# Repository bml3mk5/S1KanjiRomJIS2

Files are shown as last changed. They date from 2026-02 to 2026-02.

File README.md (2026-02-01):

# JIS第二水準内蔵漢字ROMカード for 日立MB-S1

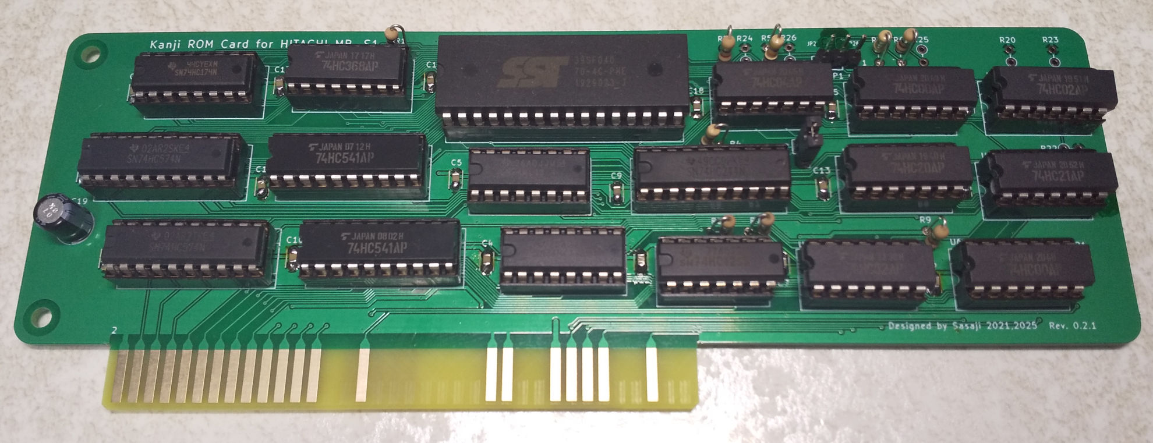
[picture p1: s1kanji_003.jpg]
KanjiROMCard

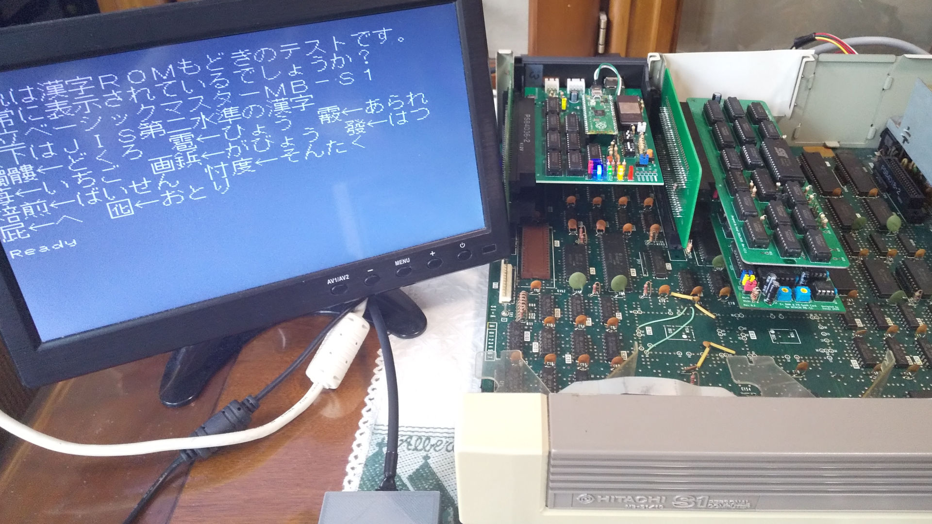
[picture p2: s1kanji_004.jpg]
Install to the MB-S1 and test it


## フォルダ構成

    Board/ ......................... 基板設計
    Documents/ ..................... 説明書など

-----
# JIS Level 2 Kanji Insided Kanji ROM Card for HITACHI MB-S1

## Folders

    Board/ ......................... The circuit board design
    Documents/ ..................... User's Manual etc.

-----
 MailTo: Sasaji (sasaji@s-sasaji.ddo.jp)
 * My Webpage: http://s-sasaji.ddo.jp/bml3mk5/
 * GitHub:     https://github.com/bml3mk5/S1KanjiRomJIS2
 * X(Twitter): https://x.com/bml3mk5

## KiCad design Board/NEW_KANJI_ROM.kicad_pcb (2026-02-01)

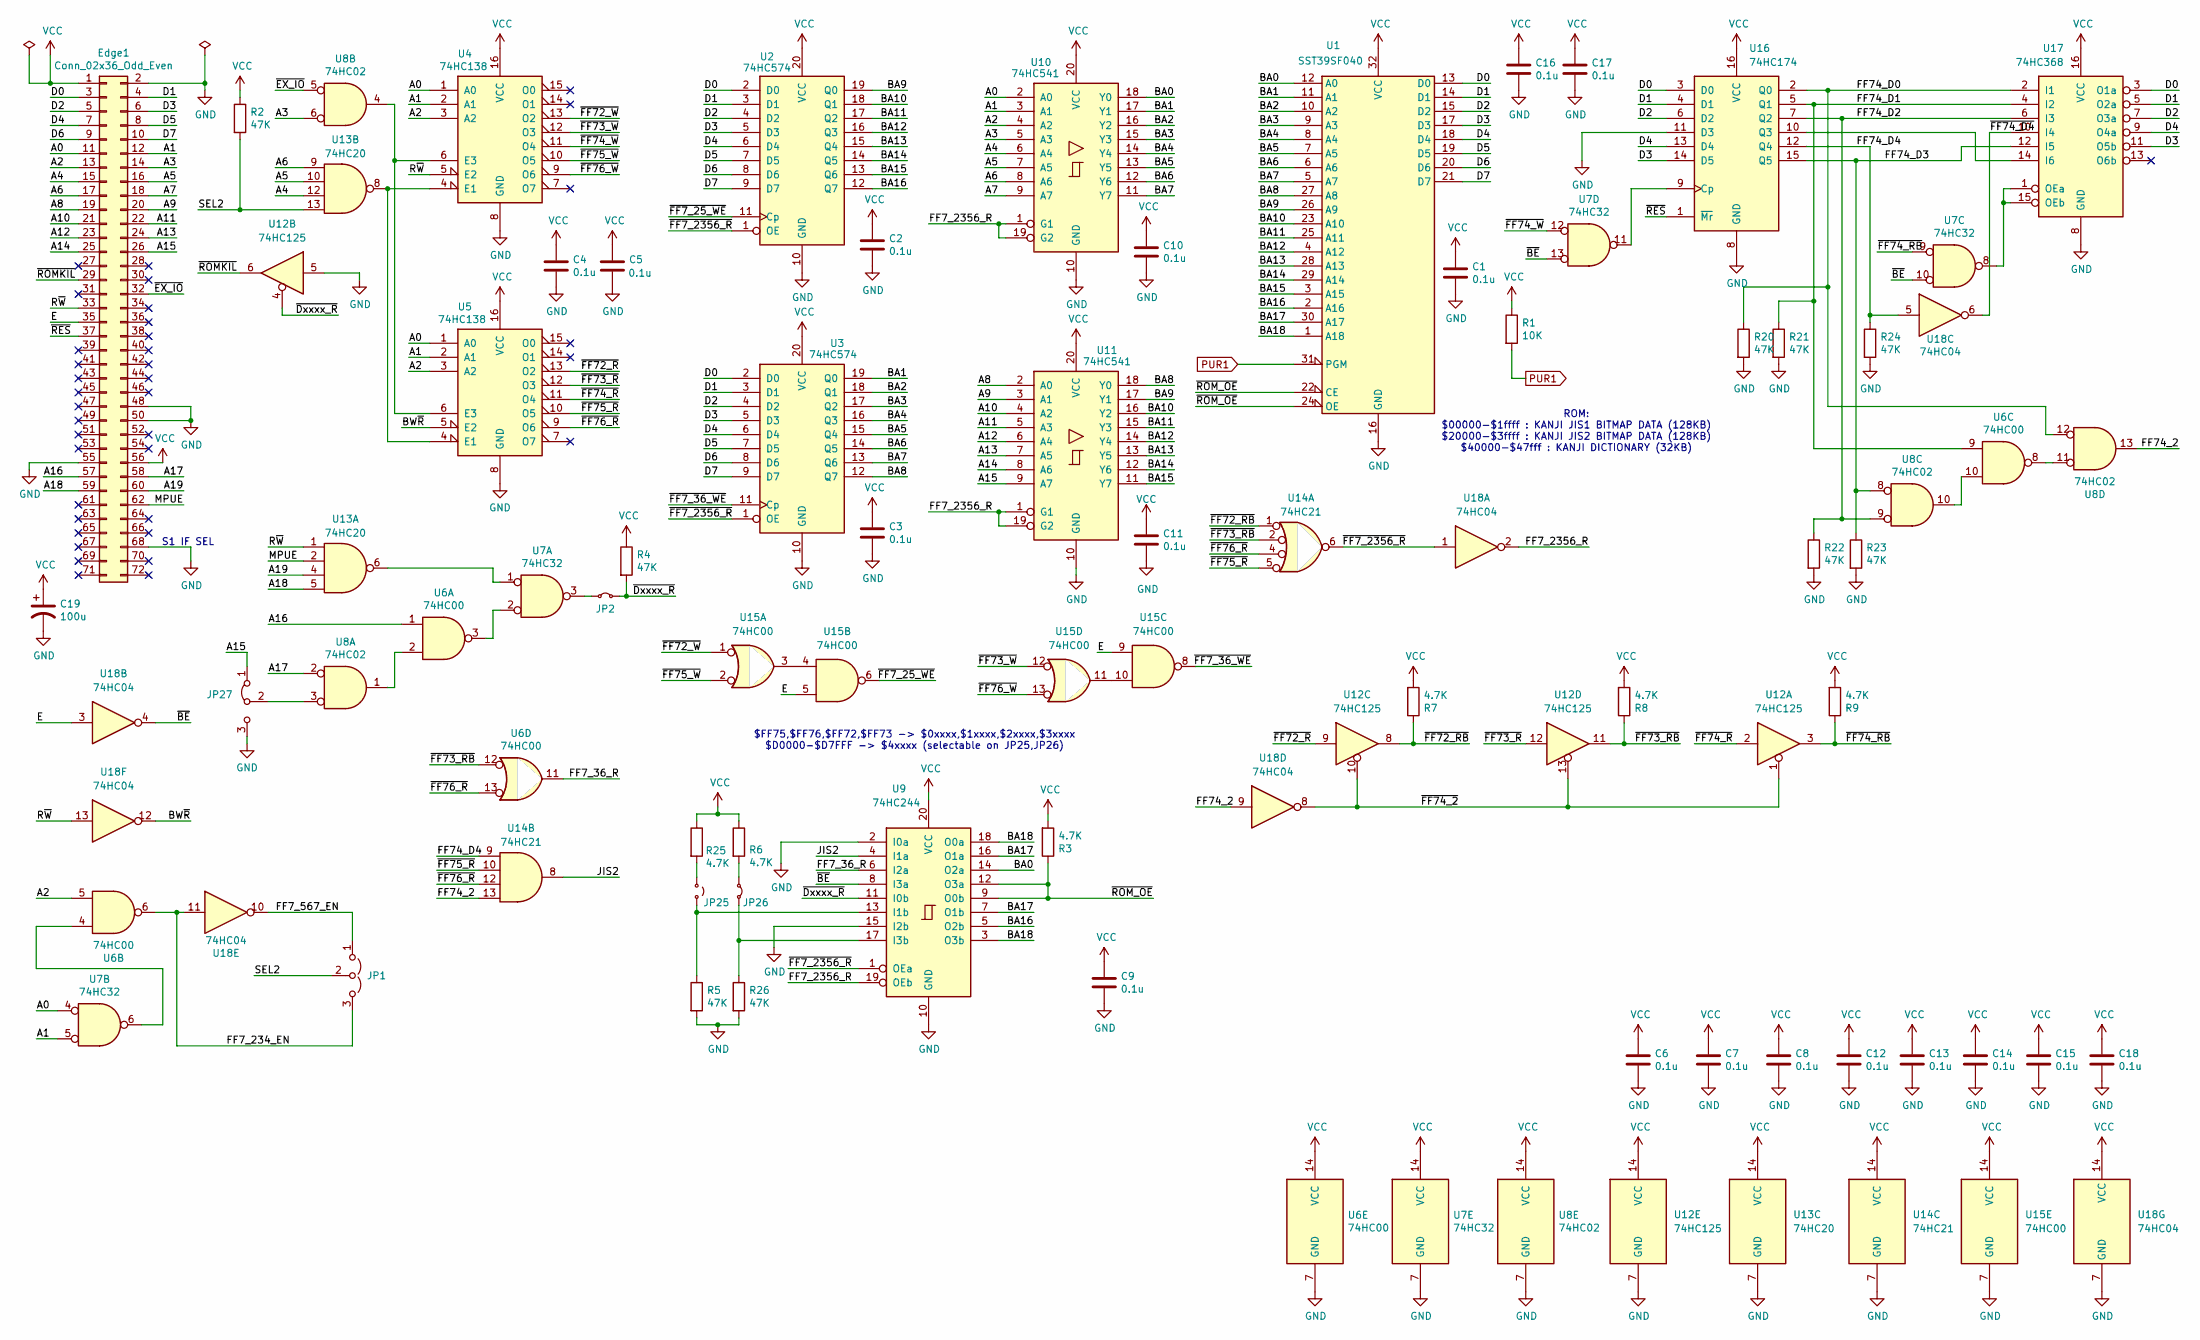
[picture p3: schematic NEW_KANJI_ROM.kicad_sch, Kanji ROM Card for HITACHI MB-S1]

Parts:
C1, C2, C3, C4, C5, C6, C7, C8, C9, C10, C11, C12, C13, C14, C15, C16, C17, C18: 0.1u; C_Disc_D3.0mm_W2.0mm_P2.50mm
C19: 100u; CP_Radial_D6.3mm_P2.50mm
Edge1: Conn_02x36_Odd_Even; CardEdge72T
JP1: Jumper_3_Open; PinHeader_1x03_P2.54mm_Vertical
JP2: Jumper_2_Small_Bridged; PinHeader_1x02_P2.54mm_Vertical
JP25: Jumper_2_Small_Open; My_SolderJumper-2_P1mm_Open_SquarePad0.8x1.0mm
JP26: Jumper_2_Small_Bridged; My_SolderJumper-2_P1mm_Bridged_SquarePad0.8x1.0mm
JP27: Jumper_3_Bridged12; My_SolderJumper-3_P1.3mm_Bridged12_RoundedPad1.0x1.5mm
R1: 10K; R_Axial_DIN0204_L3.6mm_D1.6mm_P2.54mm_Vertical
R2, R4, R5, R20, R21, R22, R23, R24, R26: 47K; R_Axial_DIN0204_L3.6mm_D1.6mm_P2.54mm_Vertical
R3, R6, R7, R8, R9, R25: 4.7K; R_Axial_DIN0204_L3.6mm_D1.6mm_P2.54mm_Vertical
U1: SST39SF040; DIP-32_W15.24mm_Socket
U2, U3: 74HC574; DIP-20_W7.62mm_Socket
U4, U5: 74HC138; DIP-16_W7.62mm_Socket
U6, U15: 74HC00; DIP-14_W7.62mm_Socket
U7: 74HC32; DIP-14_W7.62mm_Socket
U8: 74HC02; DIP-14_W7.62mm_Socket
U9: 74HC244; DIP-20_W7.62mm_Socket
U10, U11: 74HC541; DIP-20_W7.62mm_Socket
U12: 74HC125; DIP-14_W7.62mm_Socket
U13: 74HC20; DIP-14_W7.62mm_Socket
U14: 74HC21; DIP-14_W7.62mm_Socket
U16: 74HC174; DIP-16_W7.62mm_Socket
U17: 74HC368; DIP-16_W7.62mm_Socket
U18: 74HC04; DIP-14_W7.62mm_Socket

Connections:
/A0: Edge1.11, U4.1 (A0), U5.1 (A0), U7.4, U10.2 (A0)
/A1: Edge1.12, U4.2 (A1), U5.2 (A1), U7.5, U10.3 (A1)
/A2: Edge1.13, U4.3 (A2), U5.3 (A2), U6.5, U10.4 (A2)
/A3: Edge1.14, U8.6, U10.5 (A3)
/A4: Edge1.15, U10.6 (A4), U13.12
/A5: Edge1.16, U10.7 (A5), U13.10
/A6: Edge1.17, U10.8 (A6), U13.9
/A7: Edge1.18, U10.9 (A7)
/A8: Edge1.19, U11.2 (A0)
/A9: Edge1.20, U11.3 (A1)
/A10: Edge1.21, U11.4 (A2)
/A11: Edge1.22, U11.5 (A3)
/A12: Edge1.23, U11.6 (A4)
/A13: Edge1.24, U11.7 (A5)
/A14: Edge1.25, U11.8 (A6)
/A15: Edge1.26, JP27.1 (A), U11.9 (A7)
/A16: Edge1.57, U6.1
/A17: Edge1.58, U8.2
/A18: Edge1.59, U13.5
/A19: Edge1.60, U13.4
/BA0: U1.12 (A0), U9.14 (O2a), U10.18 (Y0)
/BA1: U1.11 (A1), U3.19 (Q0), U10.17 (Y1)
/BA2: U1.10 (A2), U3.18 (Q1), U10.16 (Y2)
/BA3: U1.9 (A3), U3.17 (Q2), U10.15 (Y3)
/BA4: U1.8 (A4), U3.16 (Q3), U10.14 (Y4)
/BA5: U1.7 (A5), U3.15 (Q4), U10.13 (Y5)
/BA6: U1.6 (A6), U3.14 (Q5), U10.12 (Y6)
/BA7: U1.5 (A7), U3.13 (Q6), U10.11 (Y7)
/BA8: U1.27 (A8), U3.12 (Q7), U11.18 (Y0)
/BA9: U1.26 (A9), U2.19 (Q0), U11.17 (Y1)
/BA10: U1.23 (A10), U2.18 (Q1), U11.16 (Y2)
/BA11: U1.25 (A11), U2.17 (Q2), U11.15 (Y3)
/BA12: U1.4 (A12), U2.16 (Q3), U11.14 (Y4)
/BA13: U1.28 (A13), U2.15 (Q4), U11.13 (Y5)
/BA14: U1.29 (A14), U2.14 (Q5), U11.12 (Y6)
/BA15: U1.3 (A15), U2.13 (Q6), U11.11 (Y7)
/BA16: U1.2 (A16), U2.12 (Q7), U9.5 (O2b)
/BA17: U1.30 (A17), U9.7 (O1b), U9.16 (O1a)
/BA18: U1.1 (A18), U9.3 (O3b), U9.18 (O0a)
/BW~R: U5.5 (E2), U18.12
/D0: Edge1.3, U1.13 (D0), U2.2 (D0), U3.2 (D0), U16.3 (D0), U17.3 (O1a)
/D1: Edge1.4, U1.14 (D1), U2.3 (D1), U3.3 (D1), U16.4 (D1), U17.5 (O2a)
/D2: Edge1.5, U1.15 (D2), U2.4 (D2), U3.4 (D2), U16.6 (D2), U17.7 (O3a)
/D3: Edge1.6, U1.17 (D3), U2.5 (D3), U3.5 (D3), U16.14 (D5), U17.11 (O5b)
/D4: Edge1.7, U1.18 (D4), U2.6 (D4), U3.6 (D4), U16.13 (D4), U17.9 (O4a)
/D5: Edge1.8, U1.19 (D5), U2.7 (D5), U3.7 (D5)
/D6: Edge1.9, U1.20 (D6), U2.8 (D6), U3.8 (D6)
/D7: Edge1.10, U1.21 (D7), U2.9 (D7), U3.9 (D7)
/E: Edge1.35, U15.5, U15.9, U18.3
/FF7_36_R: U6.11, U9.6 (I2a)
/FF7_234_EN: JP1.3 (B), U6.6, U18.11
/FF7_567_EN: JP1.1 (A), U18.10
/FF7_2356_R: U9.19 (OEb), U10.1 (G1), U10.19 (G2), U11.1 (G1), U11.19 (G2), U18.2
/FF74_2: U8.13, U14.13, U18.9
/FF74_D0: R20.1, U8.12, U16.2 (Q0), U17.2 (I1)
/FF74_D1: R21.1, U6.9, U16.5 (Q1), U17.4 (I2)
/FF74_D2: R22.1, U8.9, U16.7 (Q2), U17.6 (I3)
/FF74_D3: R23.1, U8.8, U16.15 (Q5), U17.12 (I5)
/FF74_D4: R24.1, U14.9, U16.12 (Q4), U18.5
/JIS2: U9.4 (I1a), U14.8
/MPUE: Edge1.62, U13.2
/R~W: Edge1.33, U4.5 (E2), U13.1, U18.13
/SEL2: JP1.2 (C), R2.2, U13.13
/~BE: U7.10, U7.13, U9.8 (I3a), U18.4
/~Dxxxx_R: JP2.2 (B), R4.2, U9.11 (I0b), U12.4
/~EX_IO: Edge1.32, U8.5
/~FF7_25_WE: U2.11 (Cp), U15.6
/~FF7_36_WE: U3.11 (Cp), U15.8
/~FF7_2356_R: U2.1 (OE), U3.1 (OE), U9.1 (OEa), U14.6, U18.1
/~FF72_RB: R7.1, U12.8, U14.1
/~FF72_R: U5.13 (O2), U12.9
/~FF72_W: U4.13 (O2), U15.1
/~FF73_RB: R8.1, U6.12, U12.11, U14.2
/~FF73_R: U5.12 (O3), U12.12
/~FF73_W: U4.12 (O3), U15.12
/~FF74_2: U12.1, U12.10, U12.13, U18.8
/~FF74_D4: U17.10 (I4), U18.6
/~FF74_RB: R9.1, U7.9, U12.3
/~FF74_R: U5.11 (O4), U12.2
/~FF74_W: U4.11 (O4), U7.12
/~FF75_R: U5.10 (O5), U14.5, U14.10
/~FF75_W: U4.10 (O5), U15.2
/~FF76_R: U5.9 (O6), U6.13, U14.4, U14.12
/~FF76_W: U4.9 (O6), U15.13
/~RES: Edge1.37, U16.1 (~Mr)
/~ROMKIL: Edge1.29, U12.6
/~ROM_OE: R3.1, U1.22 (CE), U1.24 (OE), U9.9 (O0b), U9.12 (O3a)
GND: C1.2, C2.2, C3.2, C4.2, C5.2, C6.2, C7.2, C8.2, C9.2, C10.2, C11.2, C12.2, C13.2, C14.2, C15.2, C16.2, C17.2, C18.2, C19.2, Edge1.2, Edge1.48, Edge1.50, Edge1.55, Edge1.68, JP27.3 (B), R5.2, R20.2, R21.2, R22.2, R23.2, R24.2, R26.2, U1.16 (GND), U2.10 (GND), U3.10 (GND), U4.8 (GND), U5.8 (GND), U6.7 (GND), U7.7 (GND), U8.7 (GND), U9.2 (I0a), U9.10 (GND), U9.15 (I2b), U10.10 (GND), U11.10 (GND), U12.5, U12.7 (GND), U13.7 (GND), U14.7 (GND), U15.7 (GND), U16.8 (GND), U16.11 (D3), U17.8 (GND), U18.7 (GND)
unnamed: JP2.1 (A), U7.3
unnamed: JP25.1 (A), R25.2
unnamed: JP25.2 (B), R5.1, U9.13 (I1b)
unnamed: JP26.1 (A), R6.2
unnamed: JP26.2 (B), R26.1, U9.17 (I3b)
unnamed: JP27.2 (C), U8.3
unnamed: U4.4 (E1), U5.4 (E1), U13.8
unnamed: U4.6 (E3), U5.6 (E3), U8.4
unnamed: U6.2, U8.1
unnamed: U6.3, U7.2
unnamed: U6.4, U7.6
unnamed: U6.8, U8.11
unnamed: U6.10, U8.10
unnamed: U7.1, U13.6
unnamed: U15.3, U15.4
unnamed: U15.10, U15.11
unnamed: U7.11, U16.9 (Cp)
unnamed: U16.10 (Q3), U17.14 (I6)
unnamed: U7.8, U17.1 (OEa), U17.15 (OEb)
PUR1: R1.2, U1.31 (PGM)
VCC: C1.1, C2.1, C3.1, C4.1, C5.1, C6.1, C7.1, C8.1, C9.1, C10.1, C11.1, C12.1, C13.1, C14.1, C15.1, C16.1, C17.1, C18.1, C19.1, Edge1.1, Edge1.56, R1.1, R2.1, R3.2, R4.1, R6.1, R7.2, R8.2, R9.2, R25.1, U1.32 (VCC), U2.20 (VCC), U3.20 (VCC), U4.16 (VCC), U5.16 (VCC), U6.14 (VCC), U7.14 (VCC), U8.14 (VCC), U9.20 (VCC), U10.20 (VCC), U11.20 (VCC), U12.14 (VCC), U13.14 (VCC), U14.14 (VCC), U15.14 (VCC), U16.16 (VCC), U17.16 (VCC), U18.14 (VCC)

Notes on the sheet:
S1 IF SEL
ROM: $00000-$1ffff : KANJI JIS1 BITMAP DATA (128KB) $20000-$3ffff : KANJI JIS2 BITMAP DATA (128KB) $40000-$47fff : KANJI DICTIONARY (32KB)
$FF75,$FF76,$FF72,$FF73 -> $0xxxx,$1xxxx,$2xxxx,$3xxxx $D0000-$D7FFF -> $4xxxx (selectable on JP25,JP26)

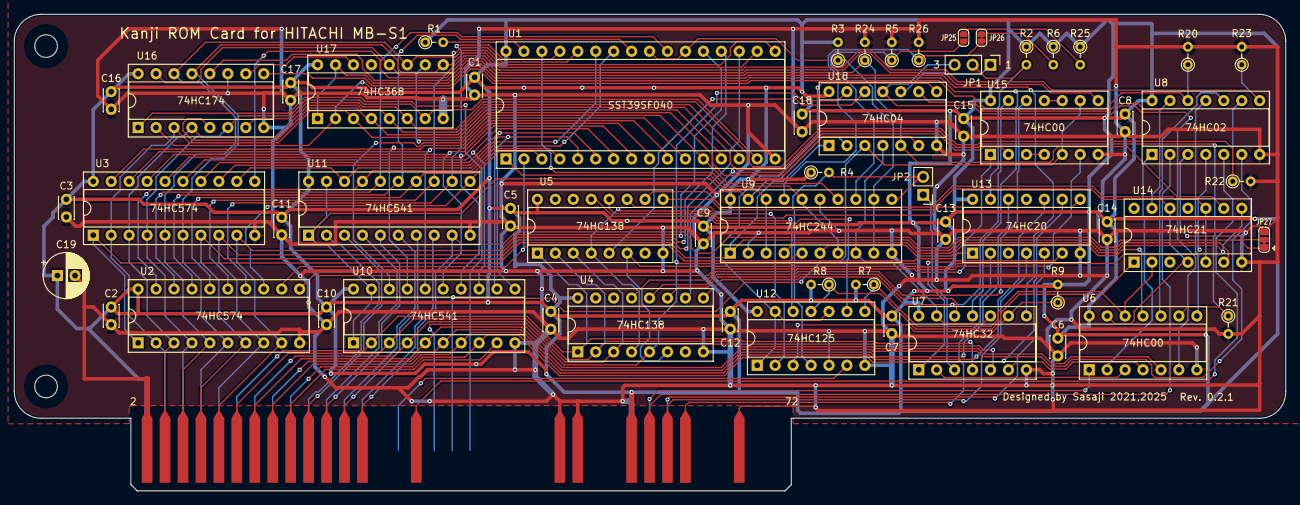
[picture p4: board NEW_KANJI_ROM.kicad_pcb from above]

Board: 2 copper layers, 180.0 x 67.5 mm, 59 parts (0 on the bottom side), 109 nets.

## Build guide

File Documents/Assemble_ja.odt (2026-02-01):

日立MB-S1用

漢字ROMもどきカード 組立説明書

Designed by Sasaji 2021,2025 Rev. 0.2.1

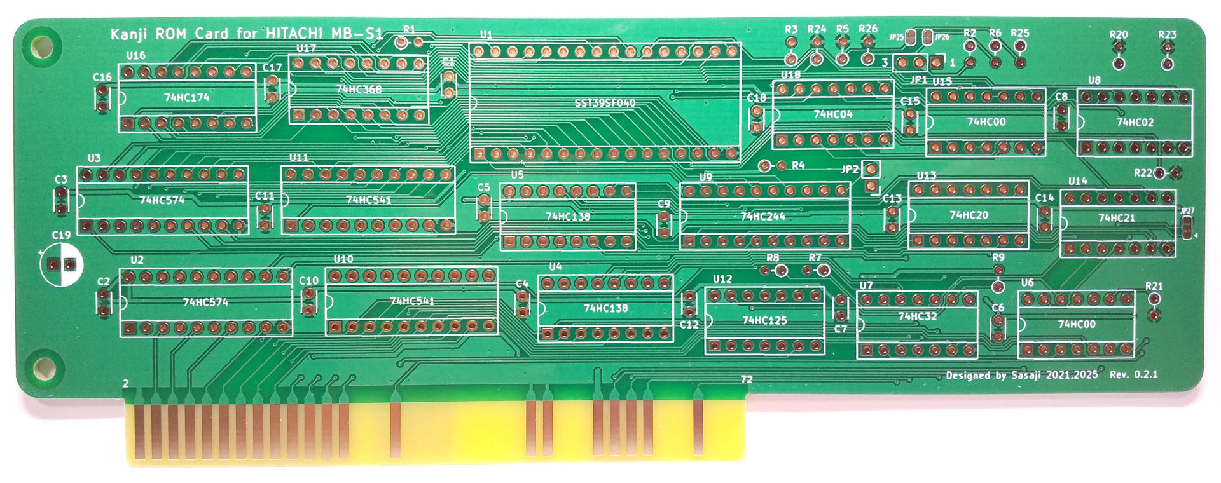
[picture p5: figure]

# 部品表

表 1: 基本部品

番号 | 部品名 | 数量 | 値など
C1～C18 | セラミックコンデンサ | 18 | 0.1uF
C19 | 電解コンデンサ | 1 | 100uF, 16V～
R1 | カーボン抵抗 | 1 | 10KΩ, 1/6W～ (2.7KΩ～10KΩで使用可能)
R2,R4,R5 | カーボン抵抗 | 3 | 47KΩ, 1/6W～ (22KΩ～47KΩで使用可能)
R3,R6,R7,R8,R9 | カーボン抵抗 | 5 | 4.7KΩ, 1/6W～ (2.7KΩ～4.7KΩで使用可能)
U1 | フラッシュメモリ(EPROM) | 1 | SST39SF040, DIP32ピン
U2,U3 | CMOSロジックIC | 2 | 74HC574, DIP20ピン
U4,U5 | CMOSロジックIC | 2 | 74HC138, DIP16ピン
U6,U15 | CMOSロジックIC | 2 | 74HC00, DIP14ピン
U7 | CMOSロジックIC | 1 | 74HC32, DIP14ピン
U8 | CMOSロジックIC | 1 | 74HC02, DIP14ピン
U9 | CMOSロジックIC | 1 | 74HC244, DIP20ピン
U10,U11 | CMOSロジックIC | 2 | 74HC541, DIP20ピン
U12 | CMOSロジックIC | 1 | 74HC125, DIP14ピン
U13 | CMOSロジックIC | 1 | 74HC20, DIP14ピン
U14 | CMOSロジックIC | 1 | 74HC21, DIP14ピン
U16 | CMOSロジックIC | 1 | 74HC174, DIP16ピン
U17 | CMOSロジックIC | 1 | 74HC368, DIP16ピン
U18 | CMOSロジックIC | 1 | 74HC04, DIP14ピン
JP1 | ピンヘッダ | 1 | 3ピン 2.54mmピッチ
JP2 | ピンヘッダ | 1 | 2ピン 2.54mmピッチ
| ジャンパピン | 1 | JP2用
U6S, U7S, U8S, U12S,U13S,U14S,U15S,U18S | ICソケット | 8 | DIP14ピン 任意
U4S, U5S, U16S, U17S | ICソケット | 4 | DIP16ピン 任意
U2S, U3S, U9S, U10S, U11S | ICソケット | 5 | DIP20ピン 任意
U1S | ICソケット | 1 | DIP32ピン 必須

表 2: JIS第二水準漢字を実装しない場合に必要な部品

番号 | 部品名 | 数量 | 値など
R20,R21,R22,R23,R24 | カーボン抵抗 | 5 | 47KΩ, 1/6W～ (22KΩ～47KΩで使用可能)
| ジャンパピン | 1 | JP1用

表 3: 辞書ROMのアドレスを変更する場合に必要な部品

番号 | 部品名 | 数量 | 値など
R25 | カーボン抵抗 | 1 | 4.7KΩ, 1/6W～ (2.7KΩ～4.7KΩで使用可能)
R26 | カーボン抵抗 | 1 | 47KΩ, 1/6W～ (22KΩ～47KΩで使用可能)

# 漢字データについて

漢字データはMBS1エミュレータに付属のmkkanji, mkdicなどを使用して作成できます。

フラッシュメモリの内容は以下のように書き込んだものを用意してください。

表 4: フラッシュメモリの内容

アドレス | 容量 | 概要 | 詳細
$00000～$1FFFF | 128KB | JIS第一水準漢字ROMイメージ | KANJI.ROMのイメージ
$20000～$3FFFF | 128KB | JIS第二水準漢字ROMイメージ | KANJI2.ROMのイメージ
$40000～$47FFF | 32KB | 漢字辞書ROMイメージ | S1DIC.ROMのイメージ

# JIS第二水準漢字を実装しない場合

JIS第二水準漢字を使用しない場合U16,U17を省略できます。ただし表 2にある抵抗を実装する必要があります。

さらに、JP1の1-2をジャンパピンでショートしてください。

# 辞書ROMのアドレスを変更する場合

フラッシュメモリ内にある辞書ROMのアドレスを変更する場合は、表 3にある抵抗を実装し、JP25,JP26を以下のように変更してください。

JP25 | JP26 | 説明
オープン | オープン | フラッシュメモリのアドレス$00000～$0FFFFをエリアにする。
ショート | オープン | フラッシュメモリのアドレス$20000～$2FFFFをエリアにする。
オープン | ショート | フラッシュメモリのアドレス$40000～$4FFFFをエリアにする(デフォルト)。
ショート | ショート | フラッシュメモリのアドレス$60000～$6FFFFをエリアにする。

また、辞書ROMのサイズを64KBにする場合は、JP27の1-2側をオープンにし、2-3側をショートしてください。デフォルトは32KBでJP27の1-2側がショートしています。

# 使い方

取扱説明書(Manual_ja.pdf)を参照してください。

# 免責事項

この基板によって発生したいかなる損害についても当方は一切責任を負いません。

この基板を使用するにあたってはすべて自己責任で行ってください。

改訂履歴

初版: 新規作成。

リンク先

この資料や基板データなどはGitHub(https://github.com/bml3mk5/) (https://github.com/bml3mk5/MP1802Gotek)に置いています。

MailTo: Sasaji (sasaji@s-sasaji.ddo.jp)

Web: http://s-sasaji.ddo.jp/bml3mk5/

X(Twitter): https://x.com/bml3mk5/

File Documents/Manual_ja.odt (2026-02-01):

日立MB-S1用

漢字ROMもどきカード　取扱説明書

Designed by Sasaji 2021,2025 Rev. 0.2.1

日立MB-S1用の拡張カードです。フラッシュメモリに漢字データを書き込むことで漢字ROMカードとして使用できます。


図 1: 外観


図 2: S1本体で動作確認

# 使い方

実機の拡張スロットに本カードを装着してください。

すでにMPC-KA01SやMPC-CM01など漢字ROMを搭載したカードと併用する場合は、装着する前にジャンパの設定を行ってください。

# レジスタ

アドレス | D7 | D6 | D5 | D4 | D3 | D2 | D1 | D0 | R/W | 説明
$FF72 | 漢字コードKA4-KA11 | | | | | | | | W | JIS第二水準漢字を出力します。 ※漢字コードはJISコードとは異なります。
| 漢字ビットマップ 左側 | | | | | | | | R(*)
$FF73 | コードKA12-KA15 | | | | ラインKA0-KA3 | | | | W
| 漢字ビットマップ 右側 | | | | | | | | R(*)
$FF74 | x | x | x | JIS2 | レジスタ有効 | | | | W | JIS第二水準漢字を有効にするか指定します。
| 1 | 1 | 1 | JIS2 | 状態 | | | | R(*)
$FF75 | 漢字コードKA4-KA11 | | | | | | | | W | JIS第一水準漢字を出力します。 ※漢字コードはJISコードとは異なります。
| 漢字ビットマップ 左側 | | | | | | | | R
$FF76 | コードKA12-KA15 | | | | ラインKA0-KA3 | | | | W
| 漢字ビットマップ 右側 | | | | | | | | R

(*) 2.1を参照のこと

## レジスタ$FF74について

$FF74のD0-D3に$2を指定することで、$FF72,$FF73,$FF74のリードが可能になります。

さらに、$FF74のD4に1を指定することで、$FF72,$FF73を介してJIS第二水準漢字データが取得できるようになります。

$FF74のリード時、D0-D3はライトした値をビット反転した値、D4はライトした値そのままが出力されます。

## JIS第一水準漢字の出力

1. $FF75に漢字コード、$FF76に漢字コードとラインを指定します。
  ※漢字コードはJISコードとは異なります。
2. $FF75にビットマップ左側、$FF76にビットマップ右側が出力されます。

## JIS第二水準漢字の出力

1. $FF74に$12を指定します。
2. $FF72に漢字コード、$FF73に漢字コードとラインを指定します。
  ※漢字コードはJISコードとは異なります。
3. $FF72にビットマップ左側、$FF73にビットマップ右側が出力されます。

# ジャンパ

## JP1 レジスタ選択

$FF72,$FF73,$FF74,$FF75,$FF76の各レジスタの有効無効を指定します。

### オープン時

すべてのレジスタが有効になります。通常はこの状態にしてください。

### ピン1-2ショート時

$FF75,$FF76のみが有効になります。JIS第二水準漢字を使用しない場合にこの設定にします。

### ピン2-3ショート時

$FF72,$FF73,$FF74のみが有効になります。JIS第一水準漢字を使用しない場合にこの設定にします。

MPC-KA01SやMPC-CM01など第一水準漢字ROMを搭載しているカードと併用する場合、この設定にしてください。

## JP2 辞書ROM選択

本カードの辞書ROMを使用する場合はここをショートします。MPC-KA01SやMPC-CM01など辞書ROMを搭載しているカードと併用する場合、ここをオープンにして本カードの辞書ROMを無効にしてください。

# 免責事項

この基板によって発生したいかなる損害についても当方は一切責任を負いません。

この基板を使用するにあたってはすべて自己責任で行ってください。

改訂履歴

初版: 新規作成。

リンク先

この資料や基板データなどはGitHub(https://github.com/bml3mk5/)に置いています。

MailTo: Sasaji (sasaji@s-sasaji.ddo.jp)

Web: http://s-sasaji.ddo.jp/bml3mk5/

X(Twitter): https://x.com/bml3mk5/
